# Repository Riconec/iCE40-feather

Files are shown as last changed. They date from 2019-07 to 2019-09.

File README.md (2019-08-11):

# iCE40-feather
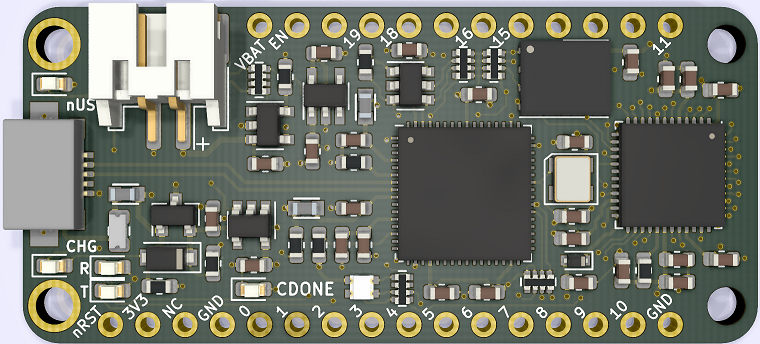
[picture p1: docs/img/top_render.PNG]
Top
  

## An iCE40UP5K FPGA in a Feather compatible form factor

* iCE40UP5k FPGA in a QFN-48 package
    * 5280 Logic Cells
* 20 IO broken out to Feather, 4 additional IO on bottom of board
* FT2232 provides programming and UART interface over a Micro USB connector
* 32 MBit SPI Flash
* Onboard RGB LED, user LED, TX/RX LEDs

### Additional FeatherWings  
* 6x6 LED Matrix + 4 Buttons + RGB LED
* DIP Switch + 7 Segment Display
* Feather to Dual PMOD breakout 

### Software
* Compatible with the open source [IceStorm](http://www.clifford.at/icestorm/#install) toolchain
* Thanks to [Piotr Esden-Tempski](https://twitter.com/esden) and his [iCEBreaker examples](https://github.com/icebreaker-fpga/icebreaker-examples) as a starting point for the firmware development.

### Additional Images
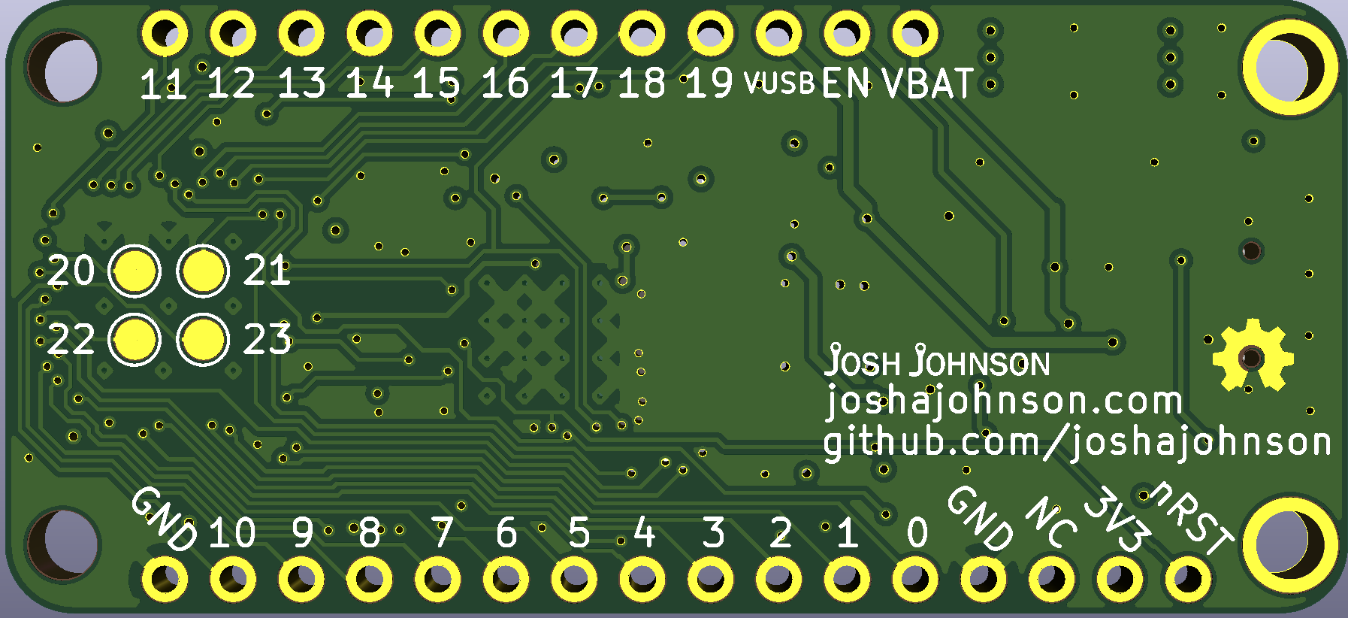
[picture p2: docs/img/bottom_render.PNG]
Bottom
  

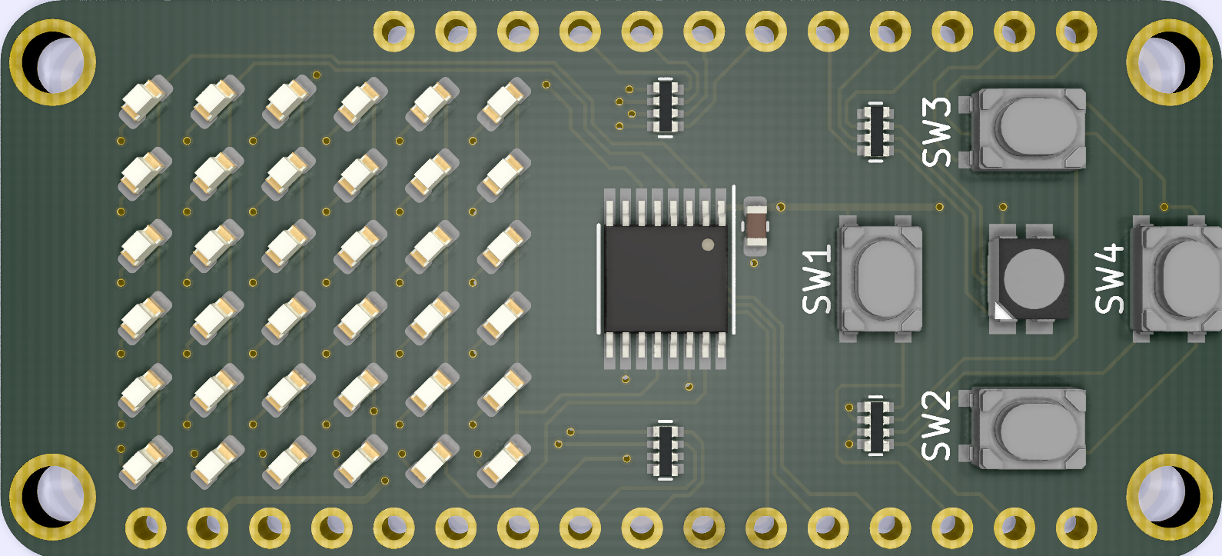
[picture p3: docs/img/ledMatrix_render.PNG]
7 Segment
  

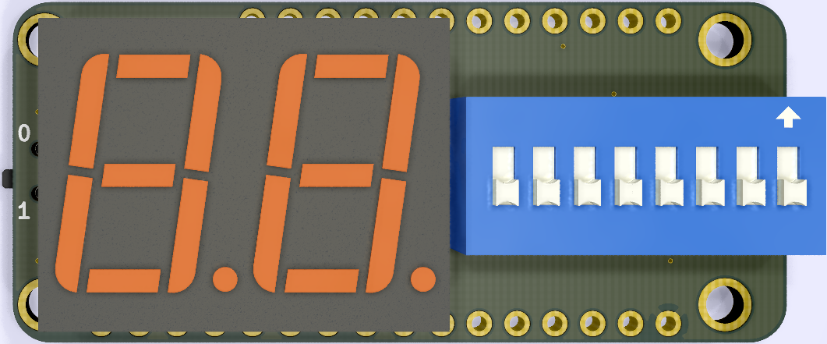
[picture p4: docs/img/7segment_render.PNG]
LED Matrix
  

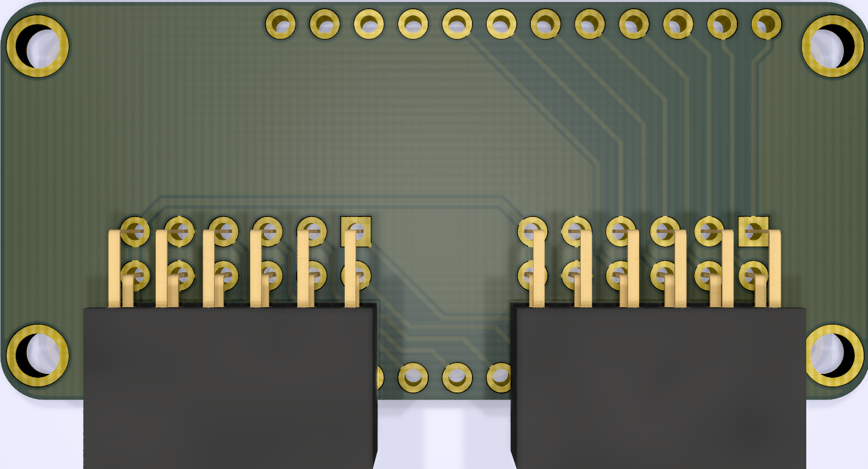
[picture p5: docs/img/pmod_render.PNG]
PMOD Breakout


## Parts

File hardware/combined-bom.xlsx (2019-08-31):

NUM BOARDS | 5
Qty | QTY Josh | QTY Order | To Order | Reference(s) | Value | LibPart | MPN
5 | 100 | 25 | 100 | C1, C2, C4, C10, C18 | 10u | Device:C | JMK107ABJ106MA-T
18 | 500 | 90 | 0 | C3, C7, C8, C11, C16, C19, C21, C22, C24, C26, C30, C31, C32, C33, C34, C35, C36 | 100n | Device:C | CL10B104KB8NNNC
2 | 30 | 10 | 0 | C5, C6 | 1u | Device:C | CL10A105MP8NNNC
1 | 30 | 5 | 0 | C28 | 4u7 | Device:C | CL10A475KQ8NNNC
1 | 50 | 5 | 0 | D1 | ORG | Device:LED | LTST-C190KFKT
1 | 3 | 5 | 10 | D2 | MBR120 | Device:D_Schottky | MBR120VLSFT1G
2 | 50 | 10 | 0 | D3, D8 | GRN | Device:LED | 150060VS75000
1 | 4 | 5 | 10 | D4 | CDBU0520 | Device:D | CDBU0520
37 | 300 | 185 | 0 | D5 | BLU | Device:LED | EAST16084BA8
1 | 100 | 5 | 0 | D6 | LED_RGBA | josh-led:LED_RGBA | LTST-C19HE1WT
1 | 100 | 5 | 0 | D7 | RED | Device:LED | SML-D12U1WT86
1 | 18 | 5 | 0 | F1 | 500mA | Device:Polyfuse | 0ZCK0050FF2E
3 | 30 | 15 | 0 | FB1, FB2, FB3 | 600R | josh-passive:Ferrite_Bead_PWR | BLM18TG601TN1D
1 | 20 | 5 | 0 | J1 | USB_B_Micro | Connector:USB_B_Micro | Josh
1 | 20 | 5 | 0 | J2 | JST_PH | Connector:Conn_01x02_Male | S2B-PH-SM4-TB(LF)(SN)
1 | 16 | 5 | 0 | Q1 | DMP2045U | Device:Q_PMOS_GSD | DMP2045U-7
2 | 20 | 10 | 0 | R1, R4 | 100K | Device:R | RMCF0603JG100K
3 | 1000 | 15 | 0 | R3, R5, R14 | 10K | Device:R | RMCF0603JT10K0
1 | 50 | 5 | 0 | R6 | 100R | Device:R | RMCF0603JT100R
1 | 50 | 5 | 0 | R13 | 2K2 | Device:R | RMCF0603JT2K20
1 | 20 | 5 | 0 | R15 | 12K | Device:R | MCR03ERTJ123
5 | 50 | 25 | 0 | RN1, RN2 | 10K | Device:R_Pack04 | RP104PJ103CS
6 | 50 | 30 | 0 | RN3 | 330R | Device:R_Pack04 | RAVF104DJT330R
2 | 50 | 10 | 0 | RN4, RN5 | 2K2 | josh-passive:RN | YC124-JR-072K2L
1 | 6 | 5 | 0 | U1 | MCP73831-2-OT | josh-power:MCP73831-2-OT | MCP73831T-2ACI/OT
1 | 3 | 5 | 2 | U2 | W25Q32JVZP | josh-memory:W25Q32JVZP | W25Q32JVZPIQ
1 | 25 | 5 | 0 | U3 | AP2112K-3.3 | Regulator_Linear:AP2112K-3.3 | AP2112K-3.3TRG1
1 | 3 | 5 | 2 | U4 | ICE40UP5K-SG48ITR | josh-ic:ICE40UP5K-SG48ITR | ICE40UP5K-SG48I
1 | 12 | 5 | 0 | U5 | NCV8114ASN120T1G | Regulator_Linear:NCV8114ASN120T1G | NCV8114ASN120T1G
1 | 5 | 5 | 0 | U6 | 93C46B | josh-memory:93C46B | 93C46BT-I/OT
1 | 4 | 5 | 1 | U7 | FT2232H | josh-ic:FT2232H | FT2232HQ-REEL
1 | 4 | 5 | 1 | X1 | DSC6101CI1A | josh-oscillator:DSC6101CI1A | DSC6101CI1A-012.0000T
1 | 4 | 5 | 1 |  | SW_DIP_x08 | Switch:SW_DIP_x08 | 78B08T
1 | 40 | 5 | 0 |  | SW_SPDT | Switch:SW_SPDT | PCM12SMTR
1 | 4 | 5 | 4 |  | LTD-5623Ax | josh-led:LTD-5623Ax | LTD-6910HR
1 | 15 | 5 | 0 |  | 74LVC2G17 | josh-logic:74LVC2G17 | SN74LVC2G17DCKR
1 | 50 | 5 | 0 |  | LED_RGBA | josh-led:LED_RGBA | Josh
4 | 50 | 20 | 0 |  | SW_Push | Switch:SW_Push | Josh
1 | 19 | 5 | 0 |  | CD74HC4050 | josh-logic:CD74HC4050 | CD74HC4050PWR

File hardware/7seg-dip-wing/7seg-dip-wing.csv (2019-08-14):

Source: | C:\Users\Josh Johnson\Dropbox\Projects\FPGA\iCE40-feather\hardware\7seg-dip-wing\7seg-dip-wing.sch
Date: | 14/08/2019 20:49:22
Tool: | Eeschema (5.1.2)-1
Generator: | C:\Program Files\KiCad\bin\scripting\plugins/bom_csv_grouped_by_value.py
Component Count: | 9
Individual Components:
Item | Qty | Reference(s) | Value | LibPart | Footprint | Datasheet
 |  | J1 | Feather | josh-connector:Feather | josh-connectors:featherwing
 |  | RN1 | 10K | Device:R_Pack04 | Resistor_SMD:R_Array_Convex_4x0402 | ~
 |  | RN2 | 10K | Device:R_Pack04 | Resistor_SMD:R_Array_Convex_4x0402 | ~
 |  | RN3 | 330R | josh-passive:RN | Resistor_SMD:R_Array_Convex_4x0402
 |  | RN4 | 330R | josh-passive:RN | Resistor_SMD:R_Array_Convex_4x0402
 |  | SW1 | SW_DIP_x08 | Switch:SW_DIP_x08 | Button_Switch_THT:SW_DIP_SPSTx08_Slide_9.78x22.5mm_W7.62mm_P2.54mm | ~
 |  | SW2 | SW_SPDT | Switch:SW_SPDT | josh-buttons-switches:SW_SPDT_PCM12 | ~
 |  | U1 | LTD-5623Ax | josh-led:LTD-5623Ax | Display_7Segment:DA56-11SEKWA | https://docs.broadcom.com/docs/AV02-1589EN
 |  | U2 | 74LVC2G17 | josh-logic:74LVC2G17 | Package_TO_SOT_SMD:SOT-363_SC-70-6
Collated Components:
Item | Qty | Reference(s) | Value | LibPart | Footprint | Datasheet
1 | 1 | J1 | Feather | josh-connector:Feather | josh-connectors:featherwing
2 | 2 | RN1, RN2 | 10K | Device:R_Pack04 | Resistor_SMD:R_Array_Convex_4x0402 | ~
3 | 2 | RN3, RN4 | 330R | josh-passive:RN | Resistor_SMD:R_Array_Convex_4x0402
4 | 1 | SW1 | SW_DIP_x08 | Switch:SW_DIP_x08 | Button_Switch_THT:SW_DIP_SPSTx08_Slide_9.78x22.5mm_W7.62mm_P2.54mm | ~
5 | 1 | SW2 | SW_SPDT | Switch:SW_SPDT | josh-buttons-switches:SW_SPDT_PCM12 | ~
6 | 1 | U1 | LTD-5623Ax | josh-led:LTD-5623Ax | Display_7Segment:DA56-11SEKWA | https://docs.broadcom.com/docs/AV02-1589EN
7 | 1 | U2 | 74LVC2G17 | josh-logic:74LVC2G17 | Package_TO_SOT_SMD:SOT-363_SC-70-6

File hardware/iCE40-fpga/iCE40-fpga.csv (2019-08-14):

Source: | C:\Users\Josh Johnson\Dropbox\Projects\FPGA\iCE40-feather\hardware\iCE40-fpga\iCE40-fpga.sch
Date: | 14/08/2019 20:48:57
Tool: | Eeschema (5.1.2)-1
Generator: | C:\Program Files\KiCad\bin\scripting\plugins/bom_csv_grouped_by_value.py
Component Count: | 62
Individual Components:
Item | Qty | Reference(s) | Value | LibPart | Footprint | Datasheet | MPN
 |  | C1 | 10u | Device:C | Capacitor_SMD:C_0603_1608Metric | ~
 |  | C2 | 10u | Device:C | Capacitor_SMD:C_0603_1608Metric | ~
 |  | C3 | 100n | Device:C | Capacitor_SMD:C_0603_1608Metric | ~
 |  | C4 | 10u | Device:C | Capacitor_SMD:C_0603_1608Metric | ~
 |  | C5 | 1u | Device:C | Capacitor_SMD:C_0603_1608Metric | ~
 |  | C6 | 1u | Device:C | Capacitor_SMD:C_0603_1608Metric | ~
 |  | C7 | 100n | Device:C | Capacitor_SMD:C_0603_1608Metric | ~
 |  | C8 | 100n | Device:C | Capacitor_SMD:C_0603_1608Metric | ~
 |  | C10 | 10u | Device:C | Capacitor_SMD:C_0603_1608Metric | ~
 |  | C11 | 100n | Device:C | Capacitor_SMD:C_0603_1608Metric | ~
 |  | C16 | 100n | Device:C | Capacitor_SMD:C_0603_1608Metric | ~
 |  | C18 | 10u | Device:C | Capacitor_SMD:C_0603_1608Metric | ~
 |  | C19 | 100n | Device:C | Capacitor_SMD:C_0603_1608Metric | ~
 |  | C21 | 100n | Device:C | Capacitor_SMD:C_0603_1608Metric | ~
 |  | C22 | 100n | Device:C | Capacitor_SMD:C_0603_1608Metric | ~
 |  | C24 | 100n | Device:C | Capacitor_SMD:C_0603_1608Metric | ~
 |  | C26 | 100n | Device:C | Capacitor_SMD:C_0603_1608Metric | ~
 |  | C28 | 4u7 | Device:C | Capacitor_SMD:C_0603_1608Metric | ~
 |  | C30 | 100n | Device:C | Capacitor_SMD:C_0603_1608Metric | ~
 |  | C31 | 100n | Device:C | Capacitor_SMD:C_0603_1608Metric | ~
 |  | C32 | 100n | Device:C | Capacitor_SMD:C_0603_1608Metric | ~
 |  | C33 | 100n | Device:C | Capacitor_SMD:C_0603_1608Metric | ~
 |  | C34 | 100n | Device:C | Capacitor_SMD:C_0603_1608Metric | ~
 |  | C35 | 100n | Device:C | Capacitor_SMD:C_0603_1608Metric | ~
 |  | C36 | 100n | Device:C | Capacitor_SMD:C_0603_1608Metric | ~
 |  | D1 | ORG | Device:LED | LED_SMD:LED_0603_1608Metric | ~
 |  | D2 | MBR120 | Device:D_Schottky | Diode_SMD:D_SOD-123F | ~
 |  | D3 | GRN | Device:LED | LED_SMD:LED_0603_1608Metric | ~
 |  | D4 | CDBU0520 | Device:D | Diode_SMD:D_SOD-523 | ~
 |  | D5 | BLU | Device:LED | LED_SMD:LED_0603_1608Metric | ~
 |  | D6 | LED_RGBA | josh-led:LED_RGBA | josh-led:LED_0606 | ~
 |  | D7 | RED | Device:LED | LED_SMD:LED_0603_1608Metric | ~
 |  | D8 | GRN | Device:LED | LED_SMD:LED_0603_1608Metric | ~
 |  | F1 | 500mA | Device:Polyfuse | josh-passives-smt:Fuse_0805_2012Metric | ~
 |  | FB1 | 600R | josh-passive:Ferrite_Bead_PWR | josh-passives-smt:Ferrite_Bead_0603 | ~
 |  | FB2 | 600R | josh-passive:Ferrite_Bead_PWR | josh-passives-smt:Ferrite_Bead_0603 | ~
 |  | FB3 | 600R | josh-passive:Ferrite_Bead_PWR | josh-passives-smt:Ferrite_Bead_0603 | ~
 |  | J1 | USB_B_Micro | Connector:USB_B_Micro | josh-connectors:USB_Micro_Aliexpress | ~
 |  | J2 | JST_PH | Connector:Conn_01x02_Male | josh-connectors:JST_PH_S2B-PH-SM4-TB_1x02-1MP_P2.00mm_Horizontal | ~
 |  | J3 | Feather | josh-connector:Feather | josh-connectors:featherwing
 |  | Q1 | DMP2045U | Device:Q_PMOS_GSD | Package_TO_SOT_SMD:SOT-23 | ~
 |  | R1 | 100K | Device:R | Resistor_SMD:R_0603_1608Metric | ~
 |  | R3 | 10K | Device:R | Resistor_SMD:R_0603_1608Metric | ~
 |  | R4 | 100K | Device:R | Resistor_SMD:R_0603_1608Metric | ~
 |  | R5 | 10K | Device:R | Resistor_SMD:R_0603_1608Metric | ~
 |  | R6 | 100R | Device:R | Resistor_SMD:R_0603_1608Metric | ~
 |  | R13 | 2K2 | Device:R | Resistor_SMD:R_0603_1608Metric | ~
 |  | R14 | 10K | Device:R | Resistor_SMD:R_0603_1608Metric | ~
 |  | R15 | 12K | Device:R | Resistor_SMD:R_0603_1608Metric | ~
 |  | RN1 | 10K | Device:R_Pack04 | Resistor_SMD:R_Array_Convex_4x0402 | ~
 |  | RN2 | 10K | Device:R_Pack04 | Resistor_SMD:R_Array_Convex_4x0402 | ~
 |  | RN3 | 330R | Device:R_Pack04 | Resistor_SMD:R_Array_Convex_4x0402 | ~
 |  | RN4 | 2K2 | josh-passive:RN | Resistor_SMD:R_Array_Convex_4x0402
 |  | RN5 | 2K2 | josh-passive:RN | Resistor_SMD:R_Array_Convex_4x0402
 |  | U1 | MCP73831-2-OT | josh-power:MCP73831-2-OT | Package_TO_SOT_SMD:SOT-23-5 | http://ww1.microchip.com/downloads/en/DeviceDoc/20001984g.pdf
 |  | U2 | W25Q32JVZP | josh-memory:W25Q32JVZP | josh-soic-sot-etc:WSON-8-1EP_6x5mm_P1.27mm_EP3.4x4.3mm | http://www.winbond.com/resource-files/w25q32jv%20revg%2003272018%20plus.pdf
 |  | U3 | AP2112K-3.3 | Regulator_Linear:AP2112K-3.3 | Package_TO_SOT_SMD:SOT-23-5 | https://www.diodes.com/assets/Datasheets/AP2112.pdf
 |  | U4 | ICE40UP5K-SG48ITR | josh-ic:ICE40UP5K-SG48ITR | josh-dfn-qfn:QFN-48-1EP_7x7mm_P0.5mm_EP5.6x5.6mm_ThermalVias | http://www.latticesemi.com/Products/FPGAandCPLD/iCE40Ultra
 |  | U5 | NCV8114ASN120T1G | Regulator_Linear:NCV8114ASN120T1G | Package_TO_SOT_SMD:TSOT-23-5 | https://ru.mouser.com/datasheet/2/308/NCV8114-D-1107616.pdf
 |  | U6 | 93C46B | josh-memory:93C46B | Package_TO_SOT_SMD:SOT-23-6 | http://ww1.microchip.com/downloads/en/DeviceDoc/20001749K.pdf
 |  | U7 | FT2232H | josh-ic:FT2232H | josh-dfn-qfn:QFN-64-1EP_9x9mm_P0.5mm_EP4.7x4.7mm_ThermalVias
 |  | X1 | DSC6101CI1A | josh-oscillator:DSC6101CI1A | josh-oscillators:CDFN_3.2x2.5mm_XO |  | DSC6101CI1A-012.0000T
Collated Components:
Item | Qty | Reference(s) | Value | LibPart | Footprint | Datasheet | MPN
1 | 5 | C1, C2, C4, C10, C18 | 10u | Device:C | Capacitor_SMD:C_0603_1608Metric | ~
2 | 17 | C3, C7, C8, C11, C16, C19, C21, C22, C24, C26, C30, C31, C32, C33, C34, C35, C36 | 100n | Device:C | Capacitor_SMD:C_0603_1608Metric | ~
3 | 2 | C5, C6 | 1u | Device:C | Capacitor_SMD:C_0603_1608Metric | ~
4 | 1 | C28 | 4u7 | Device:C | Capacitor_SMD:C_0603_1608Metric | ~
5 | 1 | D1 | ORG | Device:LED | LED_SMD:LED_0603_1608Metric | ~
6 | 1 | D2 | MBR120 | Device:D_Schottky | Diode_SMD:D_SOD-123F | ~
7 | 2 | D3, D8 | GRN | Device:LED | LED_SMD:LED_0603_1608Metric | ~
8 | 1 | D4 | CDBU0520 | Device:D | Diode_SMD:D_SOD-523 | ~
9 | 1 | D5 | BLU | Device:LED | LED_SMD:LED_0603_1608Metric | ~
10 | 1 | D6 | LED_RGBA | josh-led:LED_RGBA | josh-led:LED_0606 | ~
11 | 1 | D7 | RED | Device:LED | LED_SMD:LED_0603_1608Metric | ~
12 | 1 | F1 | 500mA | Device:Polyfuse | josh-passives-smt:Fuse_0805_2012Metric | ~
13 | 3 | FB1, FB2, FB3 | 600R | josh-passive:Ferrite_Bead_PWR | josh-passives-smt:Ferrite_Bead_0603 | ~
14 | 1 | J1 | USB_B_Micro | Connector:USB_B_Micro | josh-connectors:USB_Micro_Aliexpress | ~
15 | 1 | J2 | JST_PH | Connector:Conn_01x02_Male | josh-connectors:JST_PH_S2B-PH-SM4-TB_1x02-1MP_P2.00mm_Horizontal | ~
16 | 1 | J3 | Feather | josh-connector:Feather | josh-connectors:featherwing
17 | 1 | Q1 | DMP2045U | Device:Q_PMOS_GSD | Package_TO_SOT_SMD:SOT-23 | ~
18 | 2 | R1, R4 | 100K | Device:R | Resistor_SMD:R_0603_1608Metric | ~
19 | 3 | R3, R5, R14 | 10K | Device:R | Resistor_SMD:R_0603_1608Metric | ~
20 | 1 | R6 | 100R | Device:R | Resistor_SMD:R_0603_1608Metric | ~
21 | 1 | R13 | 2K2 | Device:R | Resistor_SMD:R_0603_1608Metric | ~
22 | 1 | R15 | 12K | Device:R | Resistor_SMD:R_0603_1608Metric | ~
23 | 2 | RN1, RN2 | 10K | Device:R_Pack04 | Resistor_SMD:R_Array_Convex_4x0402 | ~
24 | 1 | RN3 | 330R | Device:R_Pack04 | Resistor_SMD:R_Array_Convex_4x0402 | ~
25 | 2 | RN4, RN5 | 2K2 | josh-passive:RN | Resistor_SMD:R_Array_Convex_4x0402
26 | 1 | U1 | MCP73831-2-OT | josh-power:MCP73831-2-OT | Package_TO_SOT_SMD:SOT-23-5 | http://ww1.microchip.com/downloads/en/DeviceDoc/20001984g.pdf
27 | 1 | U2 | W25Q32JVZP | josh-memory:W25Q32JVZP | josh-soic-sot-etc:WSON-8-1EP_6x5mm_P1.27mm_EP3.4x4.3mm | http://www.winbond.com/resource-files/w25q32jv%20revg%2003272018%20plus.pdf
28 | 1 | U3 | AP2112K-3.3 | Regulator_Linear:AP2112K-3.3 | Package_TO_SOT_SMD:SOT-23-5 | https://www.diodes.com/assets/Datasheets/AP2112.pdf
29 | 1 | U4 | ICE40UP5K-SG48ITR | josh-ic:ICE40UP5K-SG48ITR | josh-dfn-qfn:QFN-48-1EP_7x7mm_P0.5mm_EP5.6x5.6mm_ThermalVias | http://www.latticesemi.com/Products/FPGAandCPLD/iCE40Ultra
30 | 1 | U5 | NCV8114ASN120T1G | Regulator_Linear:NCV8114ASN120T1G | Package_TO_SOT_SMD:TSOT-23-5 | https://ru.mouser.com/datasheet/2/308/NCV8114-D-1107616.pdf
31 | 1 | U6 | 93C46B | josh-memory:93C46B | Package_TO_SOT_SMD:SOT-23-6 | http://ww1.microchip.com/downloads/en/DeviceDoc/20001749K.pdf
32 | 1 | U7 | FT2232H | josh-ic:FT2232H | josh-dfn-qfn:QFN-64-1EP_9x9mm_P0.5mm_EP4.7x4.7mm_ThermalVias
33 | 1 | X1 | DSC6101CI1A | josh-oscillator:DSC6101CI1A | josh-oscillators:CDFN_3.2x2.5mm_XO |  | DSC6101CI1A-012.0000T

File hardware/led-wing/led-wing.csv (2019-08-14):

Source: | C:\Users\Josh Johnson\Dropbox\Projects\FPGA\iCE40-feather\hardware\led-wing\led-wing.sch
Date: | 14/08/2019 20:49:33
Tool: | Eeschema (5.1.2)-1
Generator: | C:\Program Files\KiCad\bin\scripting\plugins/bom_csv_grouped_by_value.py
Component Count: | 48
Individual Components:
Item | Qty | Reference(s) | Value | LibPart | Footprint | Datasheet | MPN
 |  | C1 | 100n | Device:C | Capacitor_SMD:C_0603_1608Metric | ~
 |  | D1 | LED_RGBA | josh-led:LED_RGBA | josh-led:LED_ARGB_PLCC4_1210 | ~
 |  | D2 | LED | Device:LED | josh-led:LED_0603_1608Metric_45_noSilk | ~
 |  | D3 | LED | Device:LED | josh-led:LED_0603_1608Metric_45_noSilk | ~
 |  | D4 | LED | Device:LED | josh-led:LED_0603_1608Metric_45_noSilk | ~
 |  | D5 | LED | Device:LED | josh-led:LED_0603_1608Metric_45_noSilk | ~
 |  | D6 | LED | Device:LED | josh-led:LED_0603_1608Metric_45_noSilk | ~
 |  | D7 | LED | Device:LED | josh-led:LED_0603_1608Metric_45_noSilk | ~
 |  | D8 | LED | Device:LED | josh-led:LED_0603_1608Metric_45_noSilk | ~
 |  | D9 | LED | Device:LED | josh-led:LED_0603_1608Metric_45_noSilk | ~
 |  | D10 | LED | Device:LED | josh-led:LED_0603_1608Metric_45_noSilk | ~
 |  | D11 | LED | Device:LED | josh-led:LED_0603_1608Metric_45_noSilk | ~
 |  | D12 | LED | Device:LED | josh-led:LED_0603_1608Metric_45_noSilk | ~
 |  | D13 | LED | Device:LED | josh-led:LED_0603_1608Metric_45_noSilk | ~
 |  | D14 | LED | Device:LED | josh-led:LED_0603_1608Metric_45_noSilk | ~
 |  | D15 | LED | Device:LED | josh-led:LED_0603_1608Metric_45_noSilk | ~
 |  | D16 | LED | Device:LED | josh-led:LED_0603_1608Metric_45_noSilk | ~
 |  | D17 | LED | Device:LED | josh-led:LED_0603_1608Metric_45_noSilk | ~
 |  | D18 | LED | Device:LED | josh-led:LED_0603_1608Metric_45_noSilk | ~
 |  | D19 | LED | Device:LED | josh-led:LED_0603_1608Metric_45_noSilk | ~
 |  | D20 | LED | Device:LED | josh-led:LED_0603_1608Metric_45_noSilk | ~
 |  | D21 | LED | Device:LED | josh-led:LED_0603_1608Metric_45_noSilk | ~
 |  | D22 | LED | Device:LED | josh-led:LED_0603_1608Metric_45_noSilk | ~
 |  | D23 | LED | Device:LED | josh-led:LED_0603_1608Metric_45_noSilk | ~
 |  | D24 | LED | Device:LED | josh-led:LED_0603_1608Metric_45_noSilk | ~
 |  | D25 | LED | Device:LED | josh-led:LED_0603_1608Metric_45_noSilk | ~
 |  | D26 | LED | Device:LED | josh-led:LED_0603_1608Metric_45_noSilk | ~
 |  | D27 | LED | Device:LED | josh-led:LED_0603_1608Metric_45_noSilk | ~
 |  | D28 | LED | Device:LED | josh-led:LED_0603_1608Metric_45_noSilk | ~
 |  | D29 | LED | Device:LED | josh-led:LED_0603_1608Metric_45_noSilk | ~
 |  | D30 | LED | Device:LED | josh-led:LED_0603_1608Metric_45_noSilk | ~
 |  | D31 | LED | Device:LED | josh-led:LED_0603_1608Metric_45_noSilk | ~
 |  | D32 | LED | Device:LED | josh-led:LED_0603_1608Metric_45_noSilk | ~
 |  | D33 | LED | Device:LED | josh-led:LED_0603_1608Metric_45_noSilk | ~
 |  | D34 | LED | Device:LED | josh-led:LED_0603_1608Metric_45_noSilk | ~
 |  | D35 | LED | Device:LED | josh-led:LED_0603_1608Metric_45_noSilk | ~
 |  | D36 | LED | Device:LED | josh-led:LED_0603_1608Metric_45_noSilk | ~
 |  | D37 | LED | Device:LED | josh-led:LED_0603_1608Metric_45_noSilk | ~
 |  | J1 | Feather | josh-connector:Feather | josh-connectors:featherwing
 |  | RN1 | 10K | josh-passive:RN | Resistor_SMD:R_Array_Convex_4x0402
 |  | RN2 | 330R | josh-passive:RN | Resistor_SMD:R_Array_Convex_4x0402
 |  | RN3 | 330R | josh-passive:RN | Resistor_SMD:R_Array_Convex_4x0402
 |  | RN4 | 330R | josh-passive:RN | Resistor_SMD:R_Array_Convex_4x0402
 |  | SW1 | SW_Push | Switch:SW_Push | josh-buttons-switches:BT_PTS815 | ~
 |  | SW2 | SW_Push | Switch:SW_Push | josh-buttons-switches:BT_PTS815 | ~
 |  | SW3 | SW_Push | Switch:SW_Push | josh-buttons-switches:BT_PTS815 | ~
 |  | SW4 | SW_Push | Switch:SW_Push | josh-buttons-switches:BT_PTS815 | ~
 |  | U1 | CD74HC4050 | josh-logic:CD74HC4050 | Package_SO:TSSOP-16_4.4x5mm_P0.65mm | http://www.ti.com/lit/ds/symlink/cd74hc4049.pdf | CD74HC4050PWR
Collated Components:
Item | Qty | Reference(s) | Value | LibPart | Footprint | Datasheet | MPN
1 | 1 | C1 | 100n | Device:C | Capacitor_SMD:C_0603_1608Metric | ~
2 | 1 | D1 | LED_RGBA | josh-led:LED_RGBA | josh-led:LED_ARGB_PLCC4_1210 | ~
3 | 36 | D2, D3, D4, D5, D6, D7, D8, D9, D10, D11, D12, D13, D14, D15, D16, D17, D18, D19, D20, D21, D22, D23, D24, D25, D26, D27, D28, D29, D30, D31, D32, D33, D34, D35, D36, D37 | LED | Device:LED | josh-led:LED_0603_1608Metric_45_noSilk | ~
4 | 1 | J1 | Feather | josh-connector:Feather | josh-connectors:featherwing
5 | 1 | RN1 | 10K | josh-passive:RN | Resistor_SMD:R_Array_Convex_4x0402
6 | 3 | RN2, RN3, RN4 | 330R | josh-passive:RN | Resistor_SMD:R_Array_Convex_4x0402
7 | 4 | SW1, SW2, SW3, SW4 | SW_Push | Switch:SW_Push | josh-buttons-switches:BT_PTS815 | ~
8 | 1 | U1 | CD74HC4050 | josh-logic:CD74HC4050 | Package_SO:TSSOP-16_4.4x5mm_P0.65mm | http://www.ti.com/lit/ds/symlink/cd74hc4049.pdf | CD74HC4050PWR

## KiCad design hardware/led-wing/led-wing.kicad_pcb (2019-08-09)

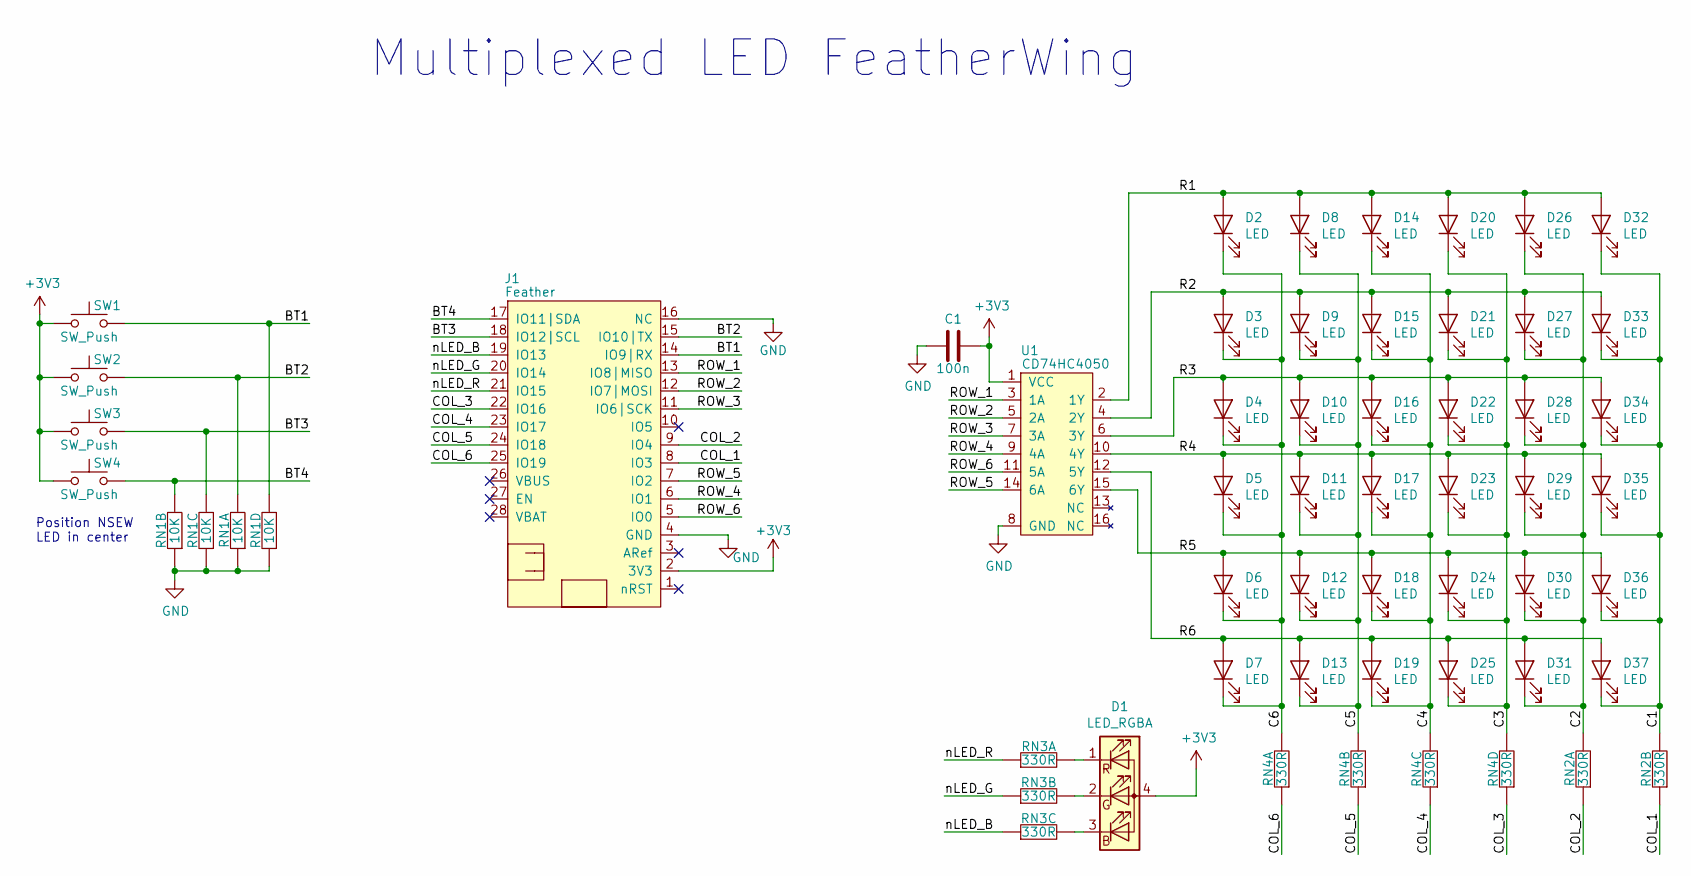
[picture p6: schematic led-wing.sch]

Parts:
C1: 100n; C_0603_1608Metric
D1: LED_RGBA; LED_ARGB_PLCC4_1210
D2, D3, D4, D5, D6, D7, D8, D9, D10, D11, D12, D13, D14, D15, D16, D17, D18, D19, D20, D21, D22, D23, D24, D25, D26, D27, D28, D29, D30, D31, D32, D33, D34, D35, D36, D37: LED; LED_0603_1608Metric_45_noSilk
J1: Feather; featherwing
RN1: 10K; R_Array_Convex_4x0402
RN2, RN3, RN4: 330R; R_Array_Convex_4x0402
SW1, SW2, SW3, SW4: SW_Push; BT_PTS815
U1: CD74HC4050; TSSOP-16_4.4x5mm_P0.65mm; MPN CD74HC4050PWR

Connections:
+3V3: C1.1, D1.4 (A), J1.2 (3V3), SW1.1, SW2.1, SW3.1, SW4.1, U1.1 (VCC)
/BT1: J1.14 (IO9|RX), RN1.8, SW1.2
/BT2: J1.15 (IO10|TX), RN1.5, SW2.2
/BT3: J1.18 (IO12|SCL), RN1.7, SW3.2
/BT4: J1.17 (IO11|SDA), RN1.6, SW4.2
/C1: D32.1 (K), D33.1 (K), D34.1 (K), D35.1 (K), D36.1 (K), D37.1 (K), RN2.6
/C2: D26.1 (K), D27.1 (K), D28.1 (K), D29.1 (K), D30.1 (K), D31.1 (K), RN2.5
/C3: D20.1 (K), D21.1 (K), D22.1 (K), D23.1 (K), D24.1 (K), D25.1 (K), RN4.8
/C4: D14.1 (K), D15.1 (K), D16.1 (K), D17.1 (K), D18.1 (K), D19.1 (K), RN4.7
/C5: D8.1 (K), D9.1 (K), D10.1 (K), D11.1 (K), D12.1 (K), D13.1 (K), RN4.6
/C6: D2.1 (K), D3.1 (K), D4.1 (K), D5.1 (K), D6.1 (K), D7.1 (K), RN4.5
/COL_1: J1.8 (IO3), RN2.3
/COL_2: J1.9 (IO4), RN2.4
/COL_3: J1.22 (IO16), RN4.1
/COL_4: J1.23 (IO17), RN4.2
/COL_5: J1.24 (IO18), RN4.3
/COL_6: J1.25 (IO19), RN4.4
/R1: D2.2 (A), D8.2 (A), D14.2 (A), D20.2 (A), D26.2 (A), D32.2 (A), U1.2 (1Y)
/R2: D3.2 (A), D9.2 (A), D15.2 (A), D21.2 (A), D27.2 (A), D33.2 (A), U1.4 (2Y)
/R3: D4.2 (A), D10.2 (A), D16.2 (A), D22.2 (A), D28.2 (A), D34.2 (A), U1.6 (3Y)
/R4: D5.2 (A), D11.2 (A), D17.2 (A), D23.2 (A), D29.2 (A), D35.2 (A), U1.10 (4Y)
/R5: D6.2 (A), D12.2 (A), D18.2 (A), D24.2 (A), D30.2 (A), D36.2 (A), U1.15 (6Y)
/R6: D7.2 (A), D13.2 (A), D19.2 (A), D25.2 (A), D31.2 (A), D37.2 (A), U1.12 (5Y)
/ROW_1: J1.13 (IO8|MISO), U1.3 (1A)
/ROW_2: J1.12 (IO7|MOSI), U1.5 (2A)
/ROW_3: J1.11 (IO6|SCK), U1.7 (3A)
/ROW_4: J1.6 (IO1), U1.9 (4A)
/ROW_5: J1.7 (IO2), U1.14 (6A)
/ROW_6: J1.5 (IO0), U1.11 (5A)
/nLED_B: J1.19 (IO13), RN3.2
/nLED_G: J1.20 (IO14), RN3.3
/nLED_R: J1.21 (IO15), RN3.4
GND: C1.2, J1.4 (GND), J1.16 (NC), RN1.1, RN1.2, RN1.3, RN1.4, U1.8 (GND)
unnamed: D1.1 (RK), RN3.5
unnamed: D1.2 (GK), RN3.6
unnamed: D1.3 (BK), RN3.7

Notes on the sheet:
Position NSEW LED in center
Multiplexed LED FeatherWing

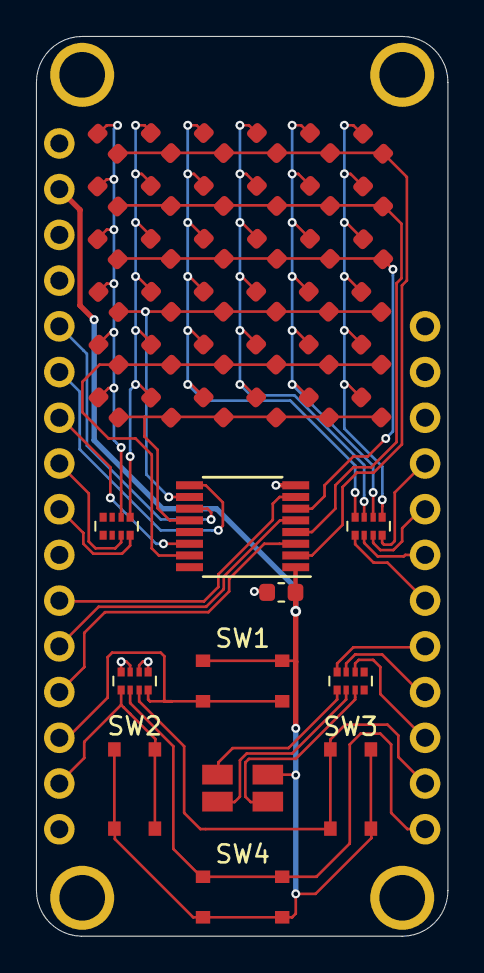
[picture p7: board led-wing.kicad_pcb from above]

Board: 2 copper layers, 22.9 x 50.0 mm, 48 parts (0 on the bottom side), 36 nets.

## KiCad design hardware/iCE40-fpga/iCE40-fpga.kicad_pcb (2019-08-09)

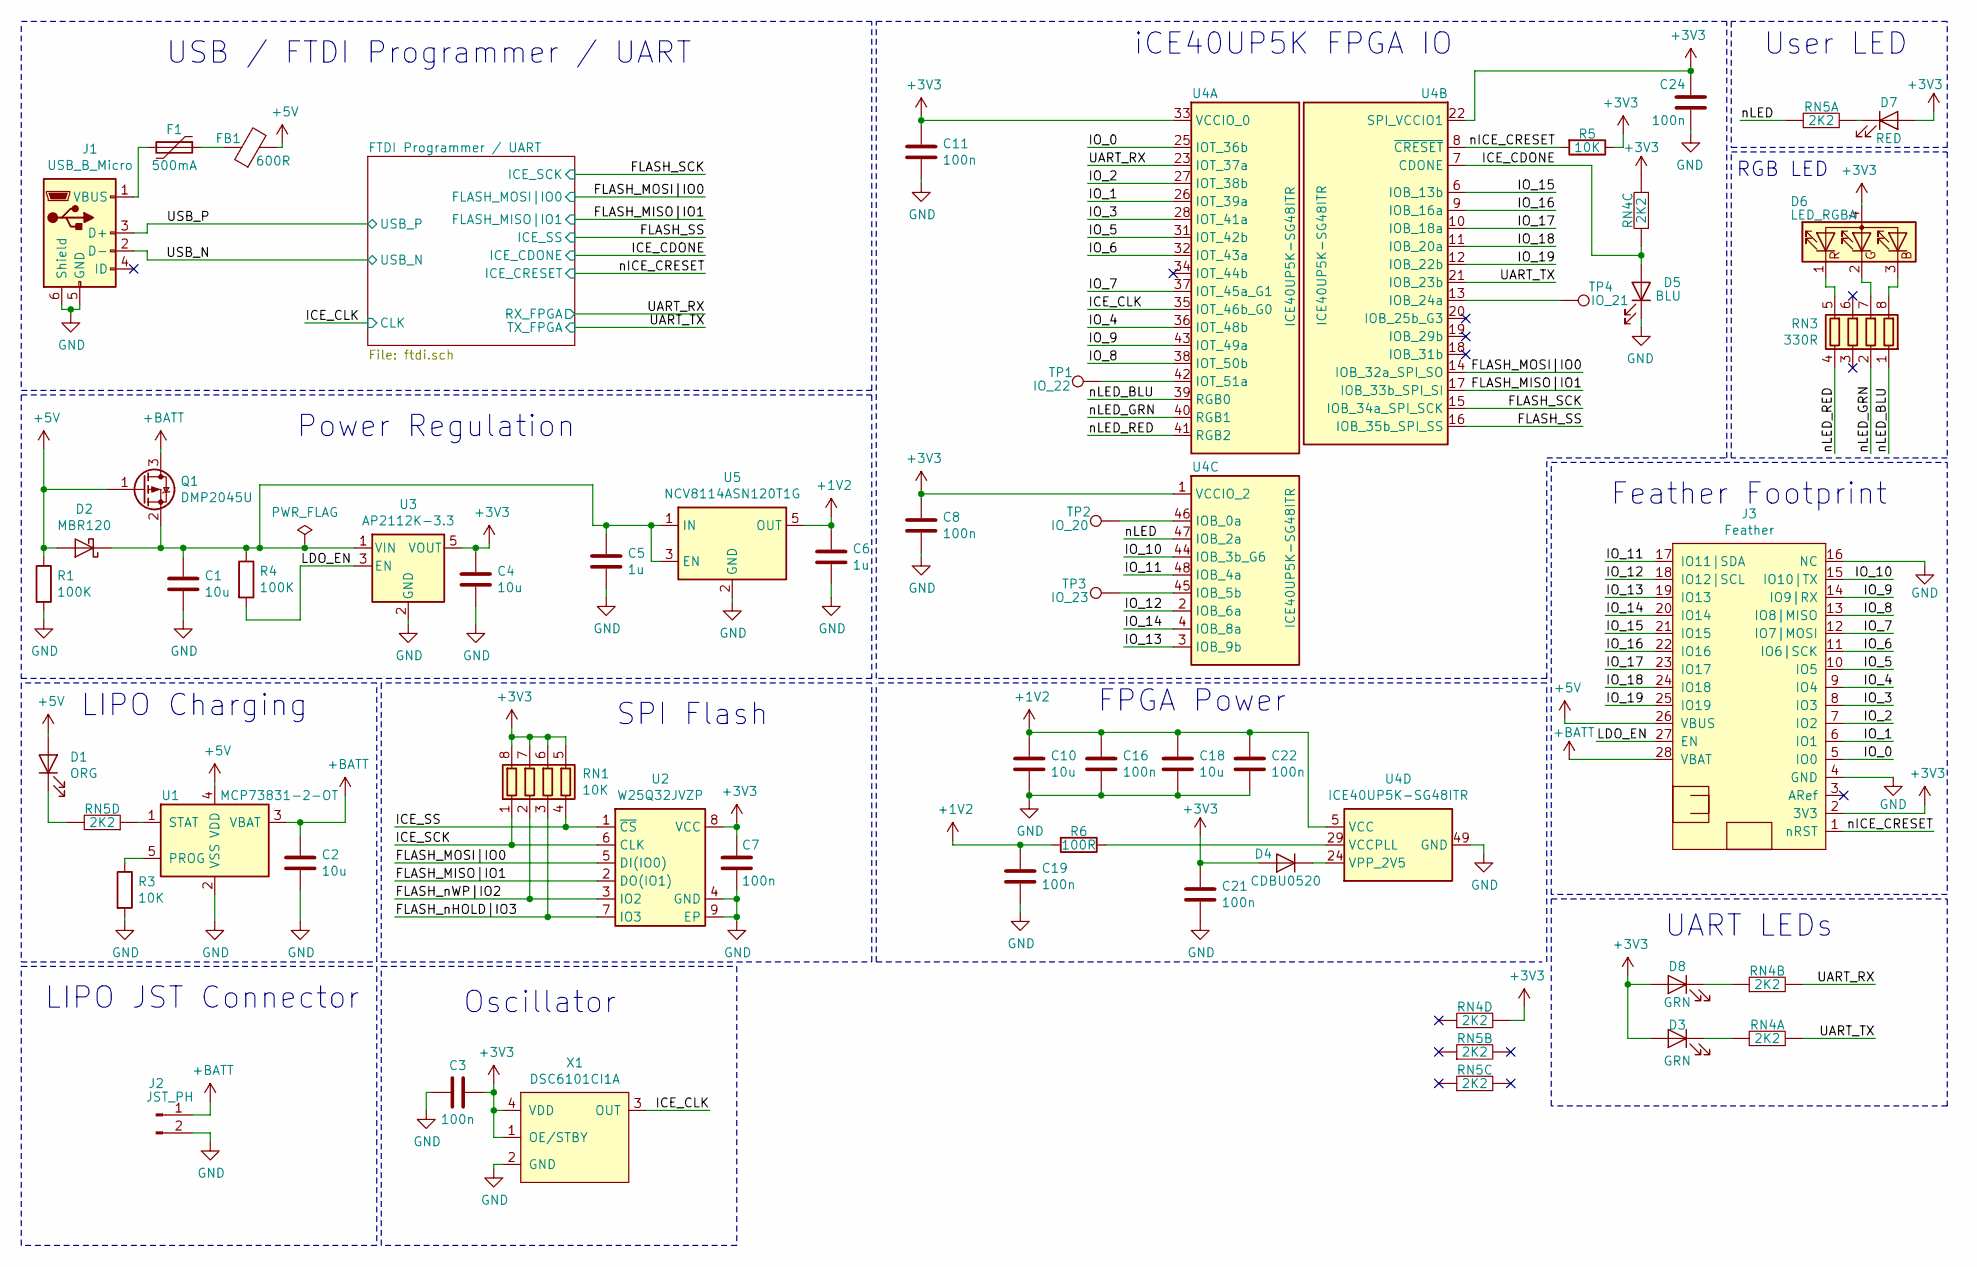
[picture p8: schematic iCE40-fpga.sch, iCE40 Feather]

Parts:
C1, C2, C4, C10, C18: 10u; C_0603_1608Metric
C3, C7, C8, C11, C16, C19, C21, C22, C24: 100n; C_0603_1608Metric
C5, C6: 1u; C_0603_1608Metric
D1: ORG; LED_0603_1608Metric
D2: MBR120; D_SOD-123F
D3, D8: GRN; LED_0603_1608Metric
D4: CDBU0520; D_SOD-523
D5: BLU; LED_0603_1608Metric
D6: LED_RGBA; LED_0606
D7: RED; LED_0603_1608Metric
F1: 500mA; Fuse_0805_2012Metric
FB1: 600R; Ferrite_Bead_0603
J1: USB_B_Micro; USB_Micro_Aliexpress
J2: JST_PH; JST_PH_S2B-PH-SM4-TB_1x02-1MP_P2.00mm_Horizontal
J3: Feather; featherwing
Q1: DMP2045U; SOT-23
R1, R4: 100K; R_0603_1608Metric
R3, R5: 10K; R_0603_1608Metric
R6: 100R; R_0603_1608Metric
RN1: 10K; R_Array_Convex_4x0402
RN3: 330R; R_Array_Convex_4x0402
RN4, RN5: 2K2; R_Array_Convex_4x0402
TP1: IO_22; TestPoint_Pad_D1.5mm
TP2: IO_20; TestPoint_Pad_D1.5mm
TP3: IO_23; TestPoint_Pad_D1.5mm
TP4: IO_21; TestPoint_Pad_D1.5mm
U1: MCP73831-2-OT; SOT-23-5
U2: W25Q32JVZP; WSON-8-1EP_6x5mm_P1.27mm_EP3.4x4.3mm
U3: AP2112K-3.3; SOT-23-5
U4: ICE40UP5K-SG48ITR; QFN-48-1EP_7x7mm_P0.5mm_EP5.6x5.6mm_ThermalVias
U5: NCV8114ASN120T1G; TSOT-23-5
X1: DSC6101CI1A; CDFN_3.2x2.5mm_XO; MPN DSC6101CI1A-012.0000T

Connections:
+1V2: C6.1, C10.1, C16.1, C18.1, C19.1, C22.1, R6.2, U4.5 (VCC), U4.30 (VCC), U5.5 (OUT)
+3V3: C3.1, C4.1, C7.1, C8.1, C11.1, C21.1, C24.1, D3.2 (A), D4.2 (A), D6.4 (A), D7.2 (A), D8.2 (A), J3.2 (3V3), R5.1, RN1.5 (R4.2), RN1.6 (R3.2), RN1.7 (R2.2), RN1.8 (R1.2), RN4.7, RN4.8, U2.8 (VCC), U3.5 (VOUT), U4.1 (VCCIO_2), U4.22 (SPI_VCCIO1), U4.33 (VCCIO_0), X1.1 (OE/STBY), X1.4 (VDD); also elsewhere on the board
+5V: D1.2 (A), D2.2 (A), FB1.2, J3.26 (VBUS), Q1.1 (G), R1.1, U1.4 (VDD)
+BATT: C2.1, J2.1, J3.28 (VBAT), Q1.3 (D), U1.3 (VBAT)
/FLASH_MISO|IO1: U2.2 (DO(IO1)), U4.17 (IOB_33b_SPI_SI); also elsewhere on the board
/FLASH_MOSI|IO0: U2.5 (DI(IO0)), U4.14 (IOB_32a_SPI_SO); also elsewhere on the board
/FLASH_SCK: RN1.1 (R1.1), U2.6 (CLK), U4.15 (IOB_34a_SPI_SCK); also elsewhere on the board
/FLASH_SS: RN1.4 (R4.1), U2.1 (~CS), U4.16 (IOB_35b_SPI_SS); also elsewhere on the board
/FLASH_nHOLD|IO3: RN1.3 (R3.1), U2.7 (IO3)
/FLASH_nWP|IO2: RN1.2 (R2.1), U2.3 (IO2)
/ICE_CDONE: D5.2 (A), RN4.2, U4.7 (CDONE); also elsewhere on the board
/ICE_CLK: U4.35 (IOT_46b_G0), X1.3 (OUT); also elsewhere on the board
/IO_0: J3.5 (IO0), U4.25 (IOT_36b)
/IO_1: J3.6 (IO1), U4.26 (IOT_39a)
/IO_2: J3.7 (IO2), U4.27 (IOT_38b)
/IO_3: J3.8 (IO3), U4.28 (IOT_41a)
/IO_4: J3.9 (IO4), U4.36 (IOT_48b)
/IO_5: J3.10 (IO5), U4.31 (IOT_42b)
/IO_6: J3.11 (IO6|SCK), U4.32 (IOT_43a)
/IO_7: J3.12 (IO7|MOSI), U4.37 (IOT_45a_G1)
/IO_8: J3.13 (IO8|MISO), U4.38 (IOT_50b)
/IO_9: J3.14 (IO9|RX), U4.43 (IOT_49a)
/IO_10: J3.15 (IO10|TX), U4.44 (IOB_3b_G6)
/IO_11: J3.17 (IO11|SDA), U4.48 (IOB_4a)
/IO_12: J3.18 (IO12|SCL), U4.2 (IOB_6a)
/IO_13: J3.19 (IO13), U4.3 (IOB_9b)
/IO_14: J3.20 (IO14), U4.4 (IOB_8a)
/IO_15: J3.21 (IO15), U4.6 (IOB_13b)
/IO_16: J3.22 (IO16), U4.9 (IOB_16a)
/IO_17: J3.23 (IO17), U4.10 (IOB_18a)
/IO_18: J3.24 (IO18), U4.11 (IOB_20a)
/IO_19: J3.25 (IO19), U4.12 (IOB_22b)
/LDO_EN: J3.27 (EN), R4.2, U3.3 (EN)
/UART_RX: RN4.6, U4.23 (IOT_37a); also elsewhere on the board
/UART_TX: RN4.5, U4.21 (IOB_23b); also elsewhere on the board
/USB_N: J1.2 (D-); also elsewhere on the board
/USB_P: J1.3 (D+); also elsewhere on the board
/nICE_CRESET: J3.1 (nRST), R5.2, U4.8 (~CRESET); also elsewhere on the board
/nLED: RN5.4, U4.47 (IOB_2a)
/nLED_BLU: RN3.1 (R1.1), U4.39 (RGB0)
/nLED_GRN: RN3.2 (R2.1), U4.40 (RGB1)
/nLED_RED: RN3.4 (R4.1), U4.41 (RGB2)
GND: C1.2, C2.2, C3.2, C4.2, C5.2, C6.2, C7.2, C8.2, C10.2, C11.2, C16.2, C18.2, C19.2, C21.2, C22.2, C24.2, D5.1 (K), J1.5 (GND), J1.6 (Shield), J2.2, J3.4 (GND), J3.16 (NC), R1.2, R3.2, U1.2 (VSS), U2.4 (GND), U2.9 (EP), U3.2 (GND), U4.49 (GND), U5.2 (GND), X1.2 (GND); also elsewhere on the board
unnamed: C1.1, C5.1, D2.1 (K), Q1.2 (S), R4.1, U3.1 (VIN), U5.1 (IN), U5.3 (EN)
unnamed: D1.1 (K), RN5.8
unnamed: D3.1 (K), RN4.4
unnamed: D4.1 (K), U4.24 (VPP_2V5)
unnamed: D6.1 (RK), RN3.5 (R4.2)
unnamed: D6.2 (GK), RN3.7 (R2.2)
unnamed: D6.3 (BK), RN3.8 (R1.2)
unnamed: D7.1 (K), RN5.5
unnamed: D8.1 (K), RN4.3
unnamed: F1.1, FB1.1
unnamed: F1.2, J1.1 (VBUS)
unnamed: R3.1, U1.5 (PROG)
unnamed: R6.1, U4.29 (VCCPLL)
unnamed: RN5.1, U1.1 (STAT)
unnamed: TP1.1, U4.42 (IOT_51a)
unnamed: TP2.1, U4.46 (IOB_0a)
unnamed: TP3.1, U4.45 (IOB_5b)
unnamed: TP4.1, U4.13 (IOB_24a)

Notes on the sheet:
Power Regulation
FPGA Power
RGB LED
SPI Flash
USB / FTDI Programmer / UART
Oscillator
iCE40UP5K FPGA IO
User LED
Feather Footprint
LIPO Charging
LIPO JST Connector
UART LEDs

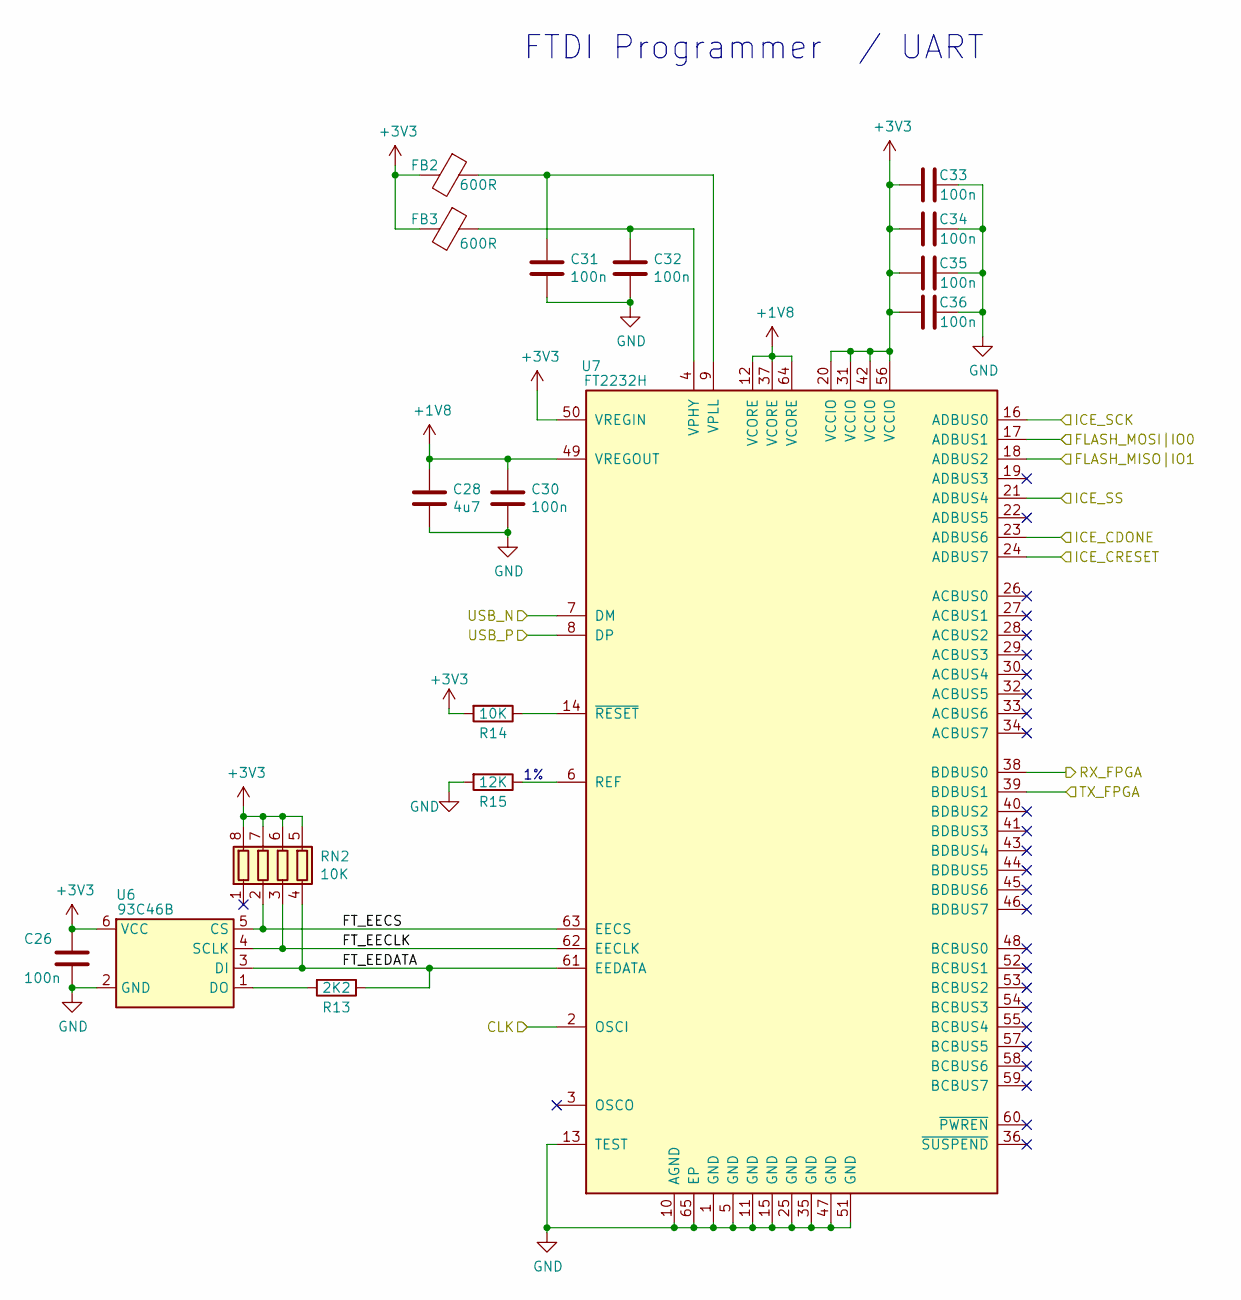
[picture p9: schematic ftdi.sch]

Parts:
C26, C30, C31, C32, C33, C34, C35, C36: 100n; C_0603_1608Metric
C28: 4u7; C_0603_1608Metric
FB2, FB3: 600R; Ferrite_Bead_0603
R13: 2K2; R_0603_1608Metric
R14: 10K; R_0603_1608Metric
R15: 12K; R_0603_1608Metric
RN2: 10K; R_Array_Convex_4x0402
U6: 93C46B; SOT-23-6
U7: FT2232H; QFN-64-1EP_9x9mm_P0.5mm_EP4.7x4.7mm_ThermalVias

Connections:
+1V8: C28.1, C30.1, U7.12 (VCORE), U7.37 (VCORE), U7.49 (VREGOUT), U7.64 (VCORE)
+3V3: C26.1, C33.2, C34.2, C35.2, C36.2, FB2.2, FB3.2, R14.2, RN2.5 (R4.2), RN2.6 (R3.2), RN2.7 (R2.2), RN2.8 (R1.2), U6.6 (VCC), U7.20 (VCCIO), U7.31 (VCCIO), U7.42 (VCCIO), U7.50 (VREGIN), U7.56 (VCCIO); also elsewhere on the board
/FLASH_MISO|IO1: U7.18 (ADBUS2); also elsewhere on the board
/FLASH_MOSI|IO0: U7.17 (ADBUS1); also elsewhere on the board
/FLASH_SCK: U7.16 (ADBUS0); also elsewhere on the board
/FLASH_SS: U7.21 (ADBUS4); also elsewhere on the board
/FTDI Programmer / UART/FT_EECLK: RN2.3 (R3.1), U6.4 (SCLK), U7.62 (EECLK)
/FTDI Programmer / UART/FT_EECS: RN2.2 (R2.1), U6.5 (CS), U7.63 (EECS)
/FTDI Programmer / UART/FT_EEDATA: R13.1, RN2.4 (R4.1), U6.3 (DI), U7.61 (EEDATA)
/ICE_CDONE: U7.23 (ADBUS6); also elsewhere on the board
/ICE_CLK: U7.2 (OSCI); also elsewhere on the board
/UART_RX: U7.38 (BDBUS0); also elsewhere on the board
/UART_TX: U7.39 (BDBUS1); also elsewhere on the board
/USB_N: U7.7 (DM); also elsewhere on the board
/USB_P: U7.8 (DP); also elsewhere on the board
/nICE_CRESET: U7.24 (ADBUS7); also elsewhere on the board
GND: C26.2, C28.2, C30.2, C31.2, C32.2, C33.1, C34.1, C35.1, C36.1, R15.2, U6.2 (GND), U7.1 (GND), U7.5 (GND), U7.10 (AGND), U7.11 (GND), U7.13 (TEST), U7.15 (GND), U7.25 (GND), U7.35 (GND), U7.47 (GND), U7.51 (GND), U7.65 (EP); also elsewhere on the board
unnamed: C31.1, FB2.1, U7.9 (VPLL)
unnamed: C32.1, FB3.1, U7.4 (VPHY)
unnamed: R13.2, U6.1 (DO)
unnamed: R14.1, U7.14 (~RESET)
unnamed: R15.1, U7.6 (REF)

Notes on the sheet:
FTDI Programmer / UART

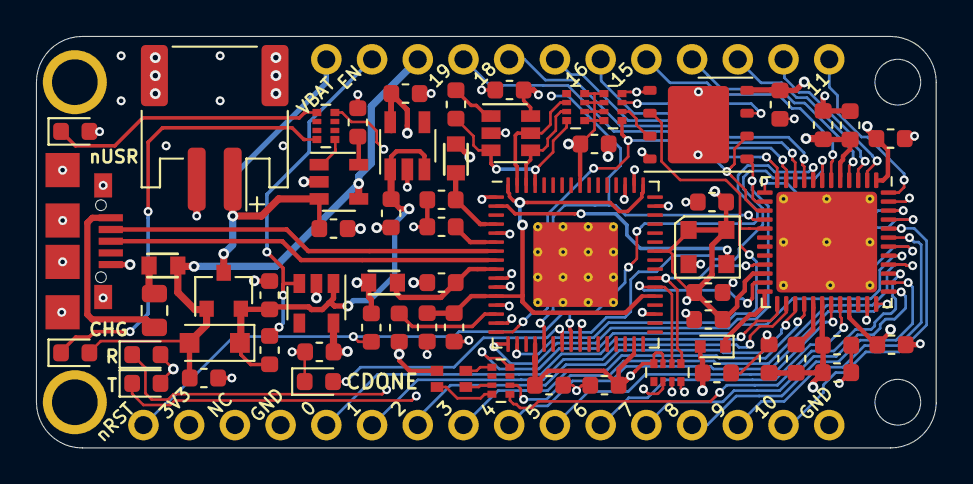
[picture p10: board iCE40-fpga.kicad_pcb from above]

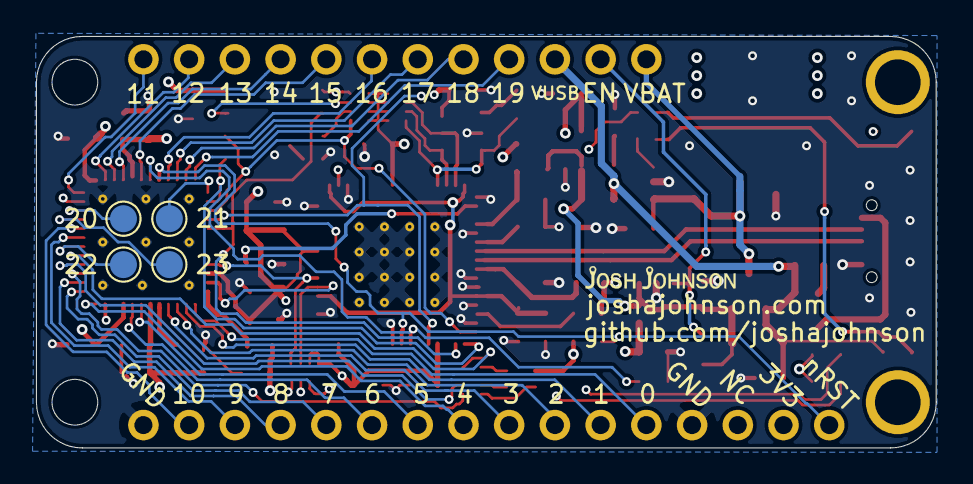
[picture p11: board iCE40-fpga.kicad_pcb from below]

Board: 4 copper layers, 50.0 x 22.9 mm, 66 parts (4 on the bottom side), 70 nets.

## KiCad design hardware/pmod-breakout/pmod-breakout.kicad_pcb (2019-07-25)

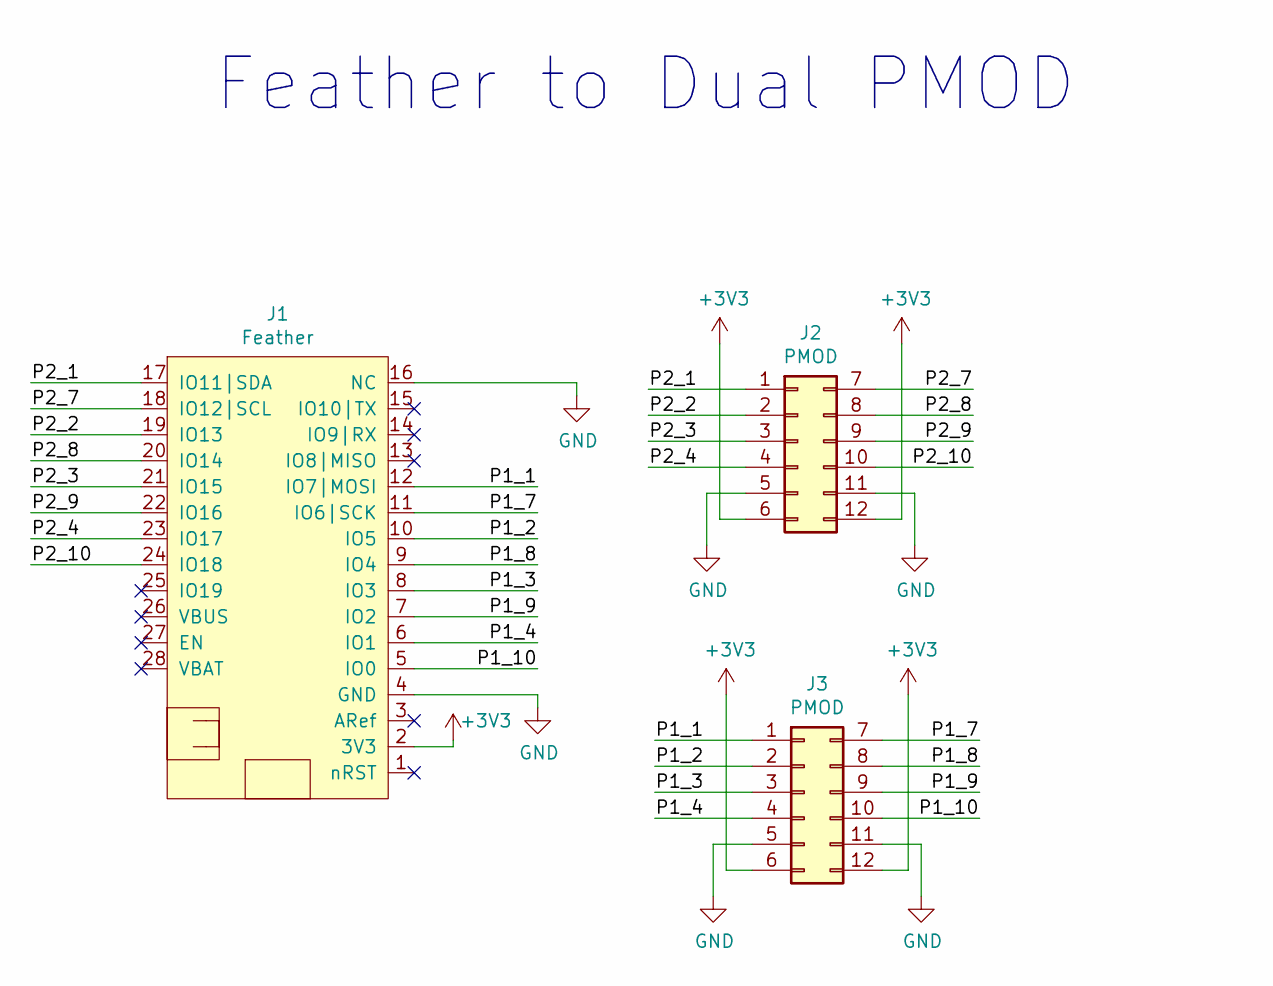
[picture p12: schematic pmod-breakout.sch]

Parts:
J1: Feather; featherwing
J2, J3: PMOD; PMOD_HOST

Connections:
+3V3: J1.2 (3V3), J2.6, J2.12, J3.6, J3.12
/P1_1: J1.12 (IO7|MOSI), J3.1
/P1_2: J1.10 (IO5), J3.2
/P1_3: J1.8 (IO3), J3.3
/P1_4: J1.6 (IO1), J3.4
/P1_7: J1.11 (IO6|SCK), J3.7
/P1_8: J1.9 (IO4), J3.8
/P1_9: J1.7 (IO2), J3.9
/P1_10: J1.5 (IO0), J3.10
/P2_1: J1.17 (IO11|SDA), J2.1
/P2_2: J1.19 (IO13), J2.2
/P2_3: J1.21 (IO15), J2.3
/P2_4: J1.23 (IO17), J2.4
/P2_7: J1.18 (IO12|SCL), J2.7
/P2_8: J1.20 (IO14), J2.8
/P2_9: J1.22 (IO16), J2.9
/P2_10: J1.24 (IO18), J2.10
GND: J1.4 (GND), J1.16 (NC), J2.5, J2.11, J3.5, J3.11

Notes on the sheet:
Feather to Dual PMOD

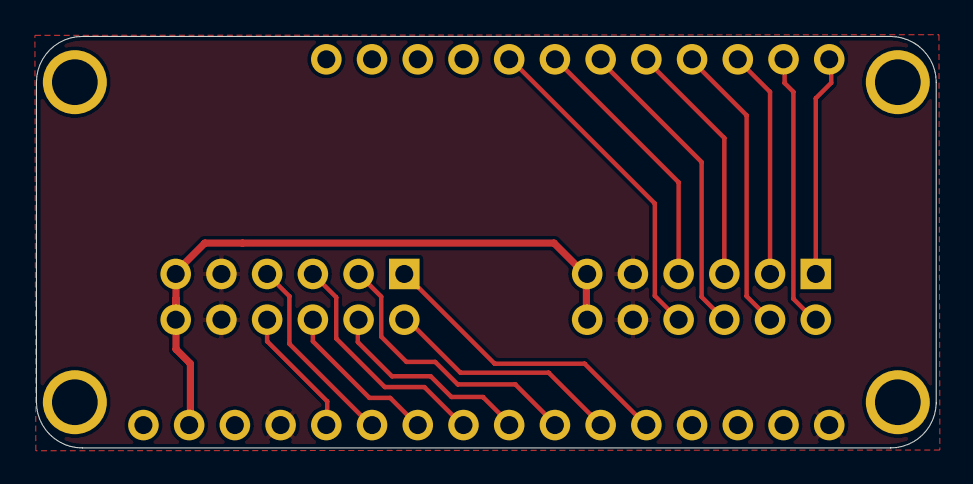
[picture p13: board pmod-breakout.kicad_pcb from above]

Board: 2 copper layers, 50.0 x 22.9 mm, 3 parts (0 on the bottom side), 18 nets.

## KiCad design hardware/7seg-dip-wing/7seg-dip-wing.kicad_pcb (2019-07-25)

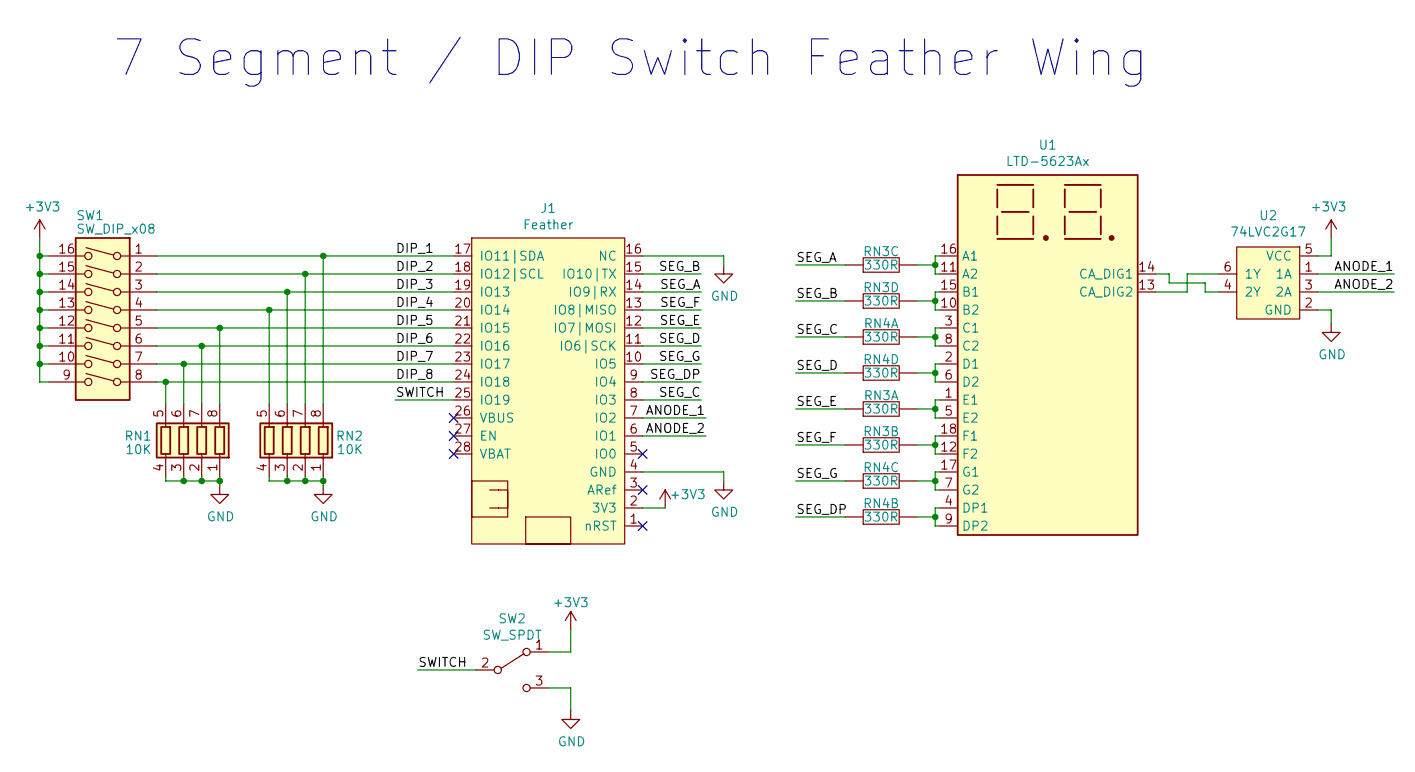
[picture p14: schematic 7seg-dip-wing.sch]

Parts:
J1: Feather; featherwing
RN1, RN2: 10K; R_Array_Convex_4x0402
RN3, RN4: 330R; R_Array_Convex_4x0402
SW1: SW_DIP_x08; SW_DIP_SPSTx08_Slide_9.78x22.5mm_W7.62mm_P2.54mm
SW2: SW_SPDT; SW_SPDT_PCM12
U1: LTD-5623Ax; DA56-11SEKWA
U2: 74LVC2G17; SOT-363_SC-70-6

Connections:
+3V3: J1.2 (3V3), SW1.9, SW1.10, SW1.11, SW1.12, SW1.13, SW1.14, SW1.15, SW1.16, SW2.1 (A), U2.5 (VCC)
/ANODE_1: J1.7 (IO2), U2.1 (1A)
/ANODE_2: J1.6 (IO1), U2.3 (2A)
/DIP_1: J1.17 (IO11|SDA), RN2.8 (R1.2), SW1.1
/DIP_2: J1.18 (IO12|SCL), RN2.7 (R2.2), SW1.2
/DIP_3: J1.19 (IO13), RN2.6 (R3.2), SW1.3
/DIP_4: J1.20 (IO14), RN2.5 (R4.2), SW1.4
/DIP_5: J1.21 (IO15), RN1.8 (R1.2), SW1.5
/DIP_6: J1.22 (IO16), RN1.7 (R2.2), SW1.6
/DIP_7: J1.23 (IO17), RN1.6 (R3.2), SW1.7
/DIP_8: J1.24 (IO18), RN1.5 (R4.2), SW1.8
/SEG_A: J1.14 (IO9|RX), RN3.2
/SEG_B: J1.15 (IO10|TX), RN3.1
/SEG_C: J1.8 (IO3), RN4.4
/SEG_D: J1.11 (IO6|SCK), RN4.1
/SEG_DP: J1.9 (IO4), RN4.3
/SEG_E: J1.12 (IO7|MOSI), RN3.4
/SEG_F: J1.13 (IO8|MISO), RN3.3
/SEG_G: J1.10 (IO5), RN4.2
/SWITCH: J1.25 (IO19), SW2.2 (B)
GND: J1.4 (GND), J1.16 (NC), RN1.1 (R1.1), RN1.2 (R2.1), RN1.3 (R3.1), RN1.4 (R4.1), RN2.1 (R1.1), RN2.2 (R2.1), RN2.3 (R3.1), RN2.4 (R4.1), SW2.3 (C), U2.2 (GND)
unnamed: RN3.5, U1.1 (E1), U1.5 (E2)
unnamed: RN3.6, U1.12 (F2), U1.18 (F1)
unnamed: RN3.7, U1.11 (A2), U1.16 (A1)
unnamed: RN3.8, U1.10 (B2), U1.15 (B1)
unnamed: RN4.5, U1.3 (C1), U1.8 (C2)
unnamed: RN4.6, U1.4 (DP1), U1.9 (DP2)
unnamed: RN4.7, U1.7 (G2), U1.17 (G1)
unnamed: RN4.8, U1.2 (D1), U1.6 (D2)
unnamed: U1.13 (CA_DIG2), U2.6 (1Y)
unnamed: U1.14 (CA_DIG1), U2.4 (2Y)

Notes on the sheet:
7 Segment / DIP Switch Feather Wing

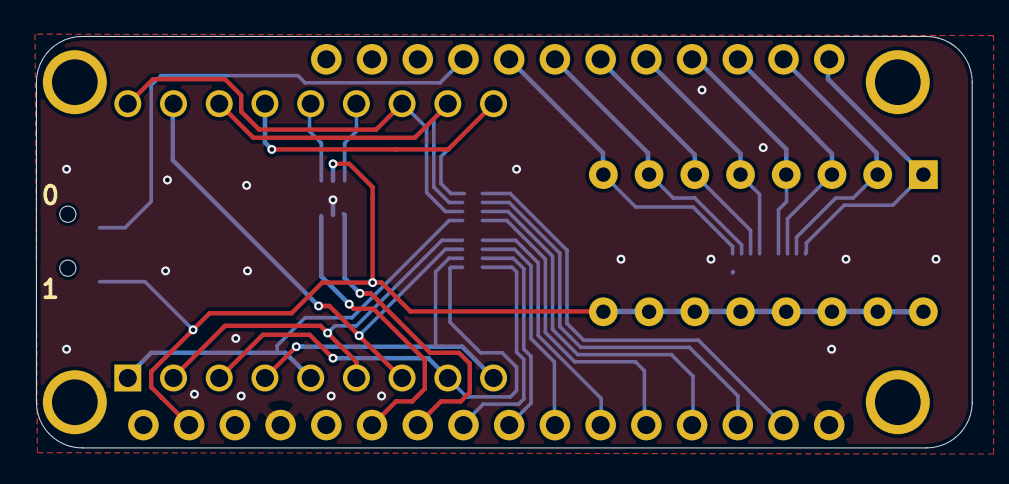
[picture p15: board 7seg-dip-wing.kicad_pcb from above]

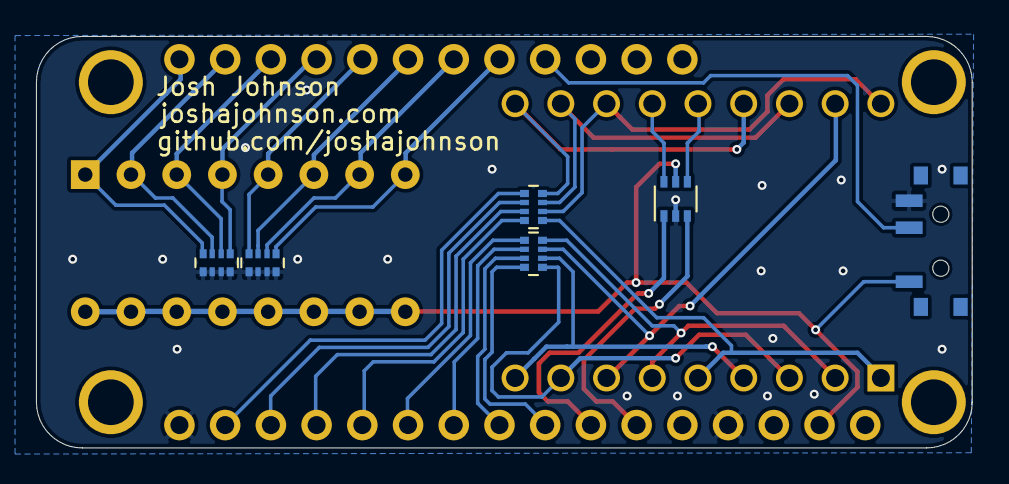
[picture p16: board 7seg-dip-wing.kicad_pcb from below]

Board: 2 copper layers, 52.0 x 22.9 mm, 9 parts (6 on the bottom side), 31 nets.

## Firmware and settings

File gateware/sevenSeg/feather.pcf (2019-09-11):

# 12 MHz clock
set_io -nowarn clk        	35

# User LED
set_io -nowarn nLED 		47

# RGB LED
set_io -nowarn nLED_RED  	41
set_io -nowarn nLED_GRN  	40
set_io -nowarn nLED_BLU  	39

# 7 Segment Pins
# In order A B C D E F G
set_io -nowarn seg[0]      	43
set_io -nowarn seg[1]      	44
set_io -nowarn seg[2]     	28
set_io -nowarn seg[3]     	32
set_io -nowarn seg[4]      	37
set_io -nowarn seg[5]     	38
set_io -nowarn seg[6]		31
set_io -nowarn dp			36

set_io -nowarn com[0]    	27
set_io -nowarn com[1]    	26

# DIP Switches
set_io -nowarn sw[0]     	48
set_io -nowarn sw[1]     	2
set_io -nowarn sw[2]     	3
set_io -nowarn sw[3]     	4
set_io -nowarn sw[4]     	6
set_io -nowarn sw[5]     	9
set_io -nowarn sw[6]     	10
set_io -nowarn sw[7]     	11

# SEL Sw
set_io -nowarn switch 		12

# GPIO
set_io -nowarn IO_0 		25
set_io -nowarn IO_1 		26
set_io -nowarn IO_2 		27
set_io -nowarn IO_3 		28
set_io -nowarn IO_4 		36
set_io -nowarn IO_5 		31
set_io -nowarn IO_6 		32
set_io -nowarn IO_7 		37
set_io -nowarn IO_8 		38
set_io -nowarn IO_9 		43
set_io -nowarn IO_10 		44
set_io -nowarn IO_11 		48
set_io -nowarn IO_12 		2
set_io -nowarn IO_13 		3
set_io -nowarn IO_14 		4
set_io -nowarn IO_15 		6
set_io -nowarn IO_16 		9
set_io -nowarn IO_17		10
set_io -nowarn IO_18		11
set_io -nowarn IO_19 		12
set_io -nowarn IO_20 		46
set_io -nowarn IO_21 		13
set_io -nowarn IO_22 		42
set_io -nowarn IO_23 		45

# UART
set_io -nowarn UART_RX 		23
set_io -nowarn UART_TX 		21

# SPI Flash
set_io -nowarn FLASH_SCK  	15
set_io -nowarn FLASH_SS  	16
set_io -nowarn FLASH_MOSI  	14
set_io -nowarn FLASH_MISO  	17

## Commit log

2019-06-24 prelim schematic done + all footprints associated
    [ftdi.sch, iCE40-fpga.kicad_pcb, iCE40-fpga.sch]
2019-06-24 fixed footprints + added extra feather headers
    [ftdi.sch, iCE40-fpga.kicad_pcb, iCE40-fpga.sch]
2019-06-24 all nets routed
    [ftdi.sch, iCE40-fpga.kicad_pcb, iCE40-fpga.sch]
2019-06-25 cleaned up routing
    [iCE40-fpga.kicad_pcb, iCE40-fpga.sch]
2019-06-26 added tx, rx leds, 7 segment and pmod wings
    [7seg-dip-wing.kicad_pcb, 7seg-dip-wing.sch, ftdi.sch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]
2019-06-26 updated board + pmod
    [iCE40-fpga.kicad_pcb, iCE40-fpga.sch, pmod-breakout.kicad_pcb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]
2019-06-26 changes to make everything work with new library setup
    [7seg-dip-wing.kicad_pcb, 7seg-dip-wing.sch, ftdi.sch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]
2019-06-26 fixing things which broke resulting from library change
    [7seg-dip-wing.kicad_pcb, 7seg-dip-wing.sch, iCE40-fpga.kicad_pcb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]
2019-07-06 added multiplexing featherwing
    [iCE40-fpga.csv, iCE40-fpga.kicad_pcb, iCE40-fpga.sch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]
2019-07-07 broke out 4 pins to TP on bottom copper
    [iCE40-fpga.kicad_pcb, iCE40-fpga.sch]
2019-07-25 generated gerbers, changed pin labelling to match constraints file
    [7seg-dip-wing-B_Cu.gbr, 7seg-dip-wing-B_Mask.gbr, 7seg-dip-wing-B_Paste.gbr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]
2019-07-25 fixed LED footprint + power supply change to support battery
    [iCE40-fpga.kicad_pcb, iCE40-fpga.sch]
2019-07-26 keep uart leds off while not in use
2019-07-28 generating BOM and costing things
    [7seg-dip-wing.csv, digikeyUpload.csv, iCE40-fpga-edited.csv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]
2019-07-29 added pdf schematics
2019-07-29 changed TX RX led direction
    [iCE40-fpga.kicad_pcb, iCE40-fpga.sch]
2019-08-05 updated feather footprint
    [iCE40-fpga.kicad_pcb]
2019-08-05 updated josh's details
    [iCE40-fpga.kicad_pcb]
2019-08-08 moved battery connector and generated new gerbers for FPGA
    [iCE40-fpga.kicad_pcb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]
2019-08-09 removed incomplete BOM
    [digikeyUpload.csv, iCE40-fpga-edited.csv]
2019-08-10 added nLED button control to led matrix wing
2019-08-14 updated BOM
    [7seg-dip-wing.csv, combined-bom.csv, iCE40-fpga.csv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]
2019-08-19 updated seven seg schematic
    [7seg-dip-wing.sch]
2019-08-31 added short readme to each module
    [combined-bom.csv, combined-bom.xlsx]
2019-09-11 Swap RGB blue / red pin assignments
    [feather.pcf]
2019-09-26 added pwm and moved gateware files
2019-10-25 uart display RX working
2020-01-07 add eeprom config to mimic lattice cable
